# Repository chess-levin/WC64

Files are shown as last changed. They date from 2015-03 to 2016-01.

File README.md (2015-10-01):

# WC64
### Yet another wordclock project

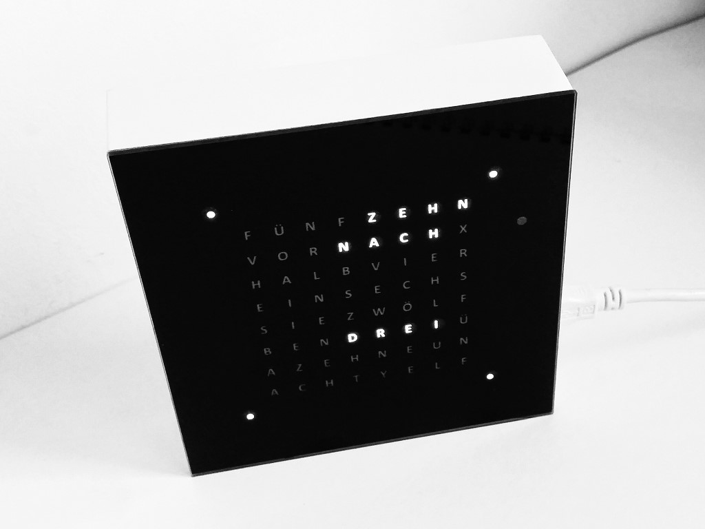
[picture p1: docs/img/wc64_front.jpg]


This is my version of a wordclock. I was trying out the arduino platform and this made so much fun, so I decided to build my own wordclock. The dimensions of my wordclock are approx. 11x11x3 cm. The front panel is hold by four strong neodym magnets. You can unclip it and turn it by 90 degress. This allows you to change the posing variant: You can hang the clock on the wall or set it on a shelf. The clock detects the environment brightness and adapts the brightness of the display to it. Find some videos of the clock on youtube [1] (https://youtu.be/Z6hiXQTgQTk), [2](https://www.youtube.com/watch?v=mQ0f72IIGkc), [3](https://www.youtube.com/watch?v=TP77dVIzgcs).

### Electronics

Techically it is based upon an [8x8 LED Matrix (WS2812B LEDs)](https://github.com/chess-levin/WC64/blob/master/docs/img/wc64_matrix.jpg), a real time clock (RTC DS3231 AT24C32 Memory Real Time Clock IIC Modul für Arduino PIC CP14003 B36) and an arduino nano board. In order to set time and date there are two push buttons inside the case.  The display is a multilayer stack of acralic glass, transparancy film, LED matrix and hard foam board. The power supply is a 2100mA USB power adapter, that connects to the arduino via mini USB cable.

### Structure

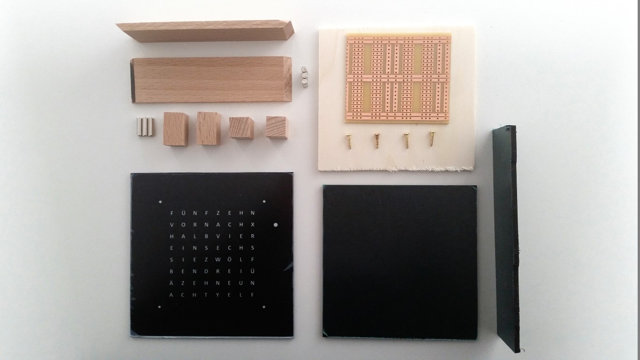
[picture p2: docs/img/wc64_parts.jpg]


The first challenge was to find a way to get [the mask](https://github.com/chess-levin/WC64/blob/master/docs/mask_final_dt.pdf) with the letters on the acrylic. For a transparency made by a cutting plotter the letters are to schmall. So I decided to have the mask printed on a transperency. The result was that the black parts were to translucent. To achieve a high contrast between the dark parts and the lighten letters I glued two transparencies together. One of the two transparencies has a self-adhesive side which it is glued to the acrylic.

The second challenge was to build a thin carrier board for the 68 LEDs and the light sensor. After some trial and error rountrips with wood I found the hard foam board. The hard foam is light, stable and most important it doesn't splinter when drilling the holes for the LEDs. The carrier board is fixed to the display with doubled sided tape.

The case is made of wood.

There are some more images, a pdf of the mask and a [circuit diagram](https://github.com/chess-levin/WC64/blob/master/docs/img/WC64_circuit.png) in the docs folder.

### Thanks

I found several ideas browsing the net for other wordclock projects. One was the [formatc1702](https://github.com/formatc1702) project of Daniel Rojas. He gave me the idea how to put all words into an 8x8 matrix. Thank you guys - keep on  wordclocking!

Have fun!

Any comments are welcome.

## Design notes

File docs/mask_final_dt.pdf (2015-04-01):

- ●
F | Ü | N | F | Z | E | H | N
V | O | R | N | A | C | H | X | ●
H | A | L | B | V | I | E | R
E | I | N | S | E | C | H | S
S | I | E | Z | W | Ö | L | F
B | E | N | D | R | E | I | Ü
Ä | Z | E | H | N | E | U | N
A | C | H | T | Y | E | L | F
- ●
- ●
F | Ü | N | F | Z | E | H | N
●
| V | O | R | N | A | C | H | X
H | A | L | B | V | I | E | R
E | I | N | S | E | C | H | S
S | I | E | Z | W | Ö | L | F
B | E | N | D | R | E | I | Ü
Ä | Z | E | H | N | E | U | N
A | C | H | T | Y | E | L | F
- ●

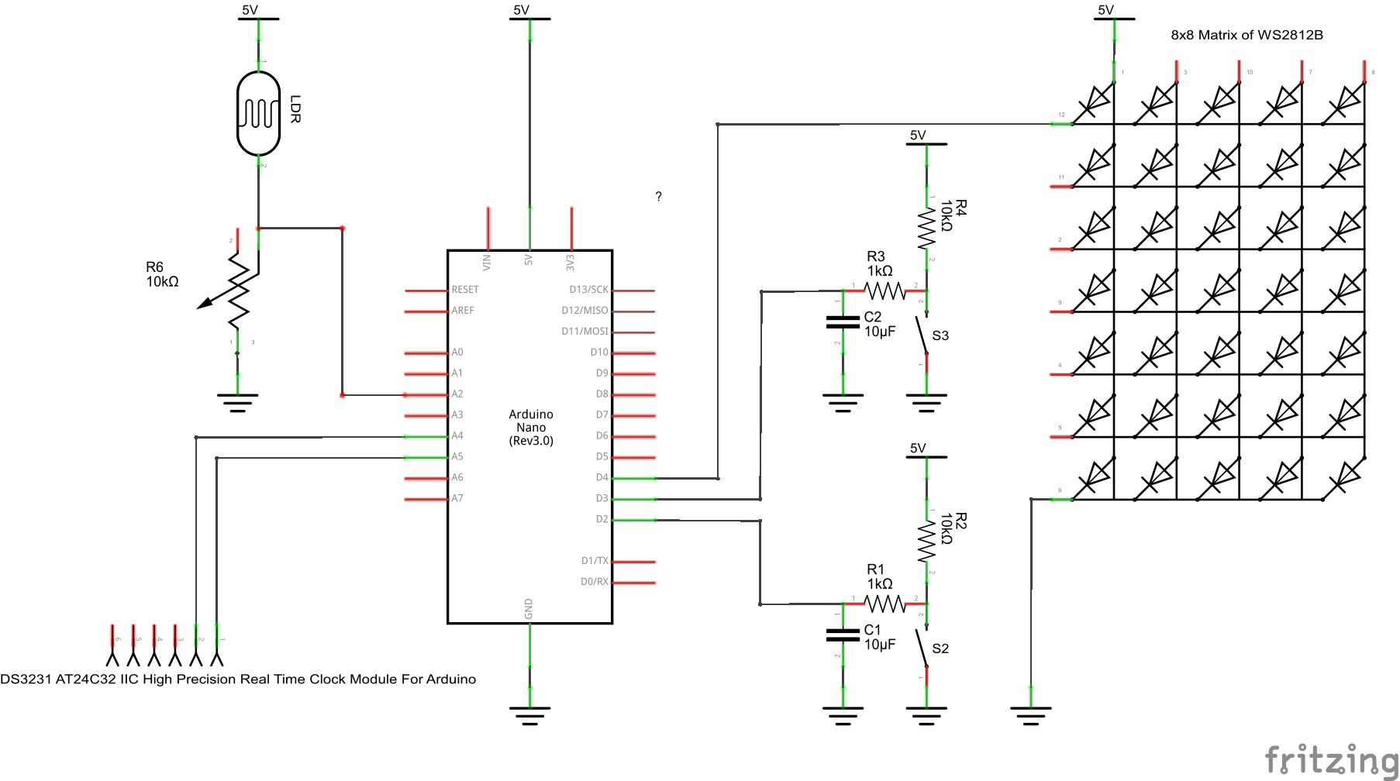
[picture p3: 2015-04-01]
docs/img/WC64_circuit.png

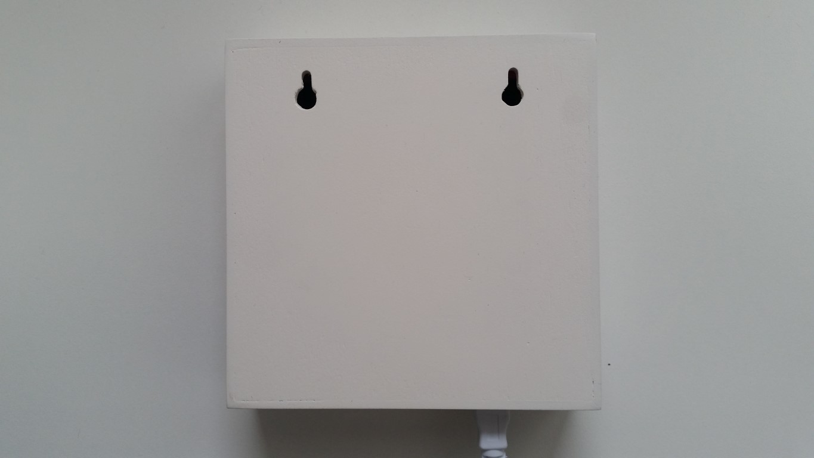
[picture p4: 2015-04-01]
docs/img/wc64_backside.jpg

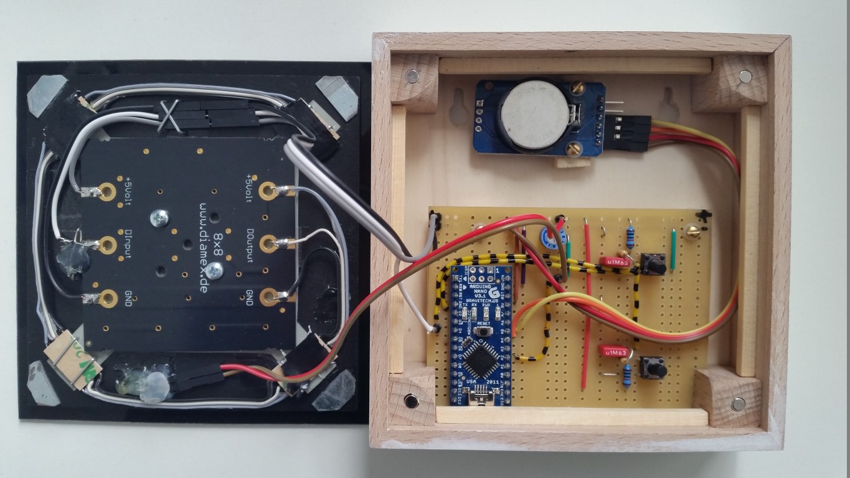
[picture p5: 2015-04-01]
docs/img/wc64_inside.jpg

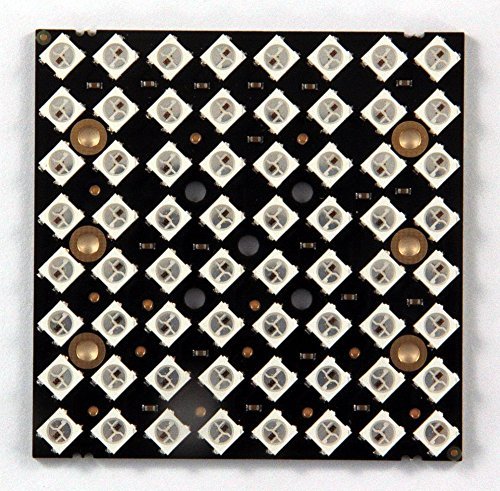
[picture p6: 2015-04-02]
docs/img/wc64_matrix.jpg

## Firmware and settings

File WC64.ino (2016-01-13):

/***************************************************************************************************************

 This sketch uses the following Libs
 
 * FastLED-3.0.3
 * ds3231-master
 
 
 (c) by Sven Scheil, 2015

*****************************************************************************************************************/

#include <avr/io.h>
#include <avr/pgmspace.h>
#include <config.h>
#include <ds3231.h>
#include <Wire.h>
#include <FastLED.h>

// Params for width and height
const uint8_t kMatrixWidth = 8;
const uint8_t kMatrixHeight = 8;
// Param for different pixel layouts
const bool kMatrixSerpentineLayout = true;
// Number of RGB LEDs in the strand
#define NUM_LEDS 68

// DC3231
#define BUFF_MAX 128
uint8_t time[8];
char recv[BUFF_MAX];
unsigned int recv_size = 0;

// Define the array of leds
CRGB leds[NUM_LEDS];
// Arduino pin used for Data
#define DATA_PIN 4

#define MAX(x, y) (((x) > (y)) ? (x) : (y))
#define MIN(x, y) (((x) < (y)) ? (x) : (y))

// Colors for display in different set modes and normal time mode
#define COLOR_NORMAL_DISPLAY CRGB( 255, 255, 255)
#define COLOR_SET_DISPLAY CRGB( 255, 136, 0)
#define COLOR_SET_DAY CRGB( 255, 0, 0); 
#define COLOR_SET_MONTH CRGB( 0, 255, 0); 
#define COLOR_SET_YEAR CRGB( 0, 0, 255);
#define LETTER_OFF 0

#define BTN_MIN_PRESSTIME 95    //doftware debouncing: ms button to be pressed before action
#define TIMEOUT_SET_MODE 30000  //ms no button pressed

#define SET_MODE_DUMMY -1
#define SET_MODE_OFF 0
#define SET_MODE_LEDTEST 1
#define SET_MODE_YEAR 2
#define SET_MODE_MONTH 3
#define SET_MODE_DAY 4
#define SET_MODE_HOURS 5
#define SET_MODE_5MINUTES 6
#define SET_MODE_1MINUTES 7
#define SET_MODE_MAX 7

volatile int setModeState = SET_MODE_OFF;

#define START_WITH_YEAR 2015  // start year setting with

#define MIN_BRIGHTNESS 4 
#define MAX_BRIGHTNESS 65

#define SET_BTN1_PIN 2      // set mode button; Interrupt 0 is on DIGITAL PIN 2!
#define SET_BTN2_PIN 3      // set value button; Interrupt 1 is on DIGITAL PIN 3!
#define SET_BTN1_IRQ 0      // set mode button; Interrupt 0 is on DIGITAL PIN 2!
#define SET_BTN2_IRQ 1      // set value button; Interrupt 1 is on DIGITAL PIN 3!

#define INTERNAL_LED_PIN 13

#define BRIGHNTNESS_SENSOR_PIN 2

#define TERM 255

const byte whone[] PROGMEM = {28,29,30,31,TERM};
const byte whtwo[] PROGMEM = {35,36,41,42,TERM};
const byte whthree[] PROGMEM = {41,42,43,44,TERM};
const byte whfour[] PROGMEM = {20,21,22,23,TERM};
const byte whfive[] PROGMEM = {39,40,55,56,TERM};
const byte whsix[] PROGMEM = {24,25,26,27,28,TERM};
const byte whseven[] PROGMEM = {32,33,34,47,46,45,TERM};
const byte wheight[] PROGMEM = {63,62,61,60,TERM};
const byte whnine[] PROGMEM = {52,53,54,55,TERM};
const byte whten[] PROGMEM = {49,50,51,52,TERM};
const byte wheleven[] PROGMEM = {56,57,58,TERM};
const byte whtwelve[] PROGMEM = {35,36,37,38,39,TERM};

const byte* const whours[] PROGMEM = {whone, whtwo, whthree, whfour, whfive, whsix, whseven, wheight, whnine, whten, wheleven, whtwelve};

const byte wmone[] PROGMEM = {66,TERM};
const byte wmtwo[] PROGMEM = {66,65,TERM};
const byte wmthree[] PROGMEM = {66,65,64,TERM};
const byte wmfour[] PROGMEM = {66,65,64,67,TERM};
const byte wmfive[] PROGMEM = {0,1,2,3,TERM};
const byte wmten[] PROGMEM = {4,5,6,7,TERM};
const byte wmfiveten[] PROGMEM = {0,1,2,3,4,5,6,7,TERM};

#define mfive_idx 4
#define mten_idx 5
#define mfiveten_idx 6

const byte* const wminutes[] PROGMEM = {wmone, wmtwo, wmthree, wmfour, wmfive, wmten, wmfiveten};

const byte wto[] PROGMEM = {13,14,15,TERM};
const byte wpast[] PROGMEM = {9,10,11,12,TERM};
const byte whalf[] PROGMEM = {16,17,18,19,TERM};

#define mto_idx 0
#define mpast_idx 1
#define mhalf_idx 2

const byte* const wtime[] PROGMEM = {wto, wpast, whalf};

byte letterMatrix[NUM_LEDS];

uint8_t minLastDisplayed = 0;

long lastPressedTime = 0;
struct ts t;

void (*animationCalback)();

#define UPDATES_PER_SECOND 8

byte startpoint[] = {0,2,3,0,1,0,2};
int averageBrigtness[] = {500,500,500,500,500,500};
byte averageBrigtnessIdx = 0;

void setup() {
  delay(3000);

  randomSeed(analogRead(0));

  FastLED.addLeds<WS2812B, DATA_PIN, GRB>(leds, NUM_LEDS);
  FastLED.clear();
  
  pinMode(INTERNAL_LED_PIN, OUTPUT);
  digitalWrite(INTERNAL_LED_PIN, LOW);  // turn LED OFF
  
  attachInterrupt(SET_BTN1_IRQ, initSetMode, RISING);
//  attachInterrupt(SET_BTN2_IRQ, setValue, RISING);
 
  pinMode(SET_BTN1_PIN, INPUT);     
  pinMode(SET_BTN2_PIN, INPUT);

  Serial.begin(9600);
  
  Wire.begin(); // init Wire Library
  DS3231_init(DS3231_INTCN);
  memset(recv, 0, BUFF_MAX);
}

void loop() {
  FastLED.show();                        // see https://github.com/FastLED/FastLED/wiki/FastLED-Temporal-Dithering

  if (setModeState == SET_MODE_OFF) {
    animationCalback = &showMatrixAnimation;
//    animationCalback = &showNoAnimation;
    getRTCData(&t);
        
    if (t.min != minLastDisplayed) {
      minLastDisplayed = t.min;
      showTime(t.hour, t.min);
    }
    delay(5000);
    readBrightnessSensor();
  
  } else {
     Serial.print(F("setModeState in main loop: "));
     Serial.println(setModeState);
     animationCalback = &showNoAnimation;
     queryButtonLoop();
     showTime(t.hour, t.min);
  }
  
}


void showAnimation( void (*animation)() ) {
  animation();
  resetLetterMatrix();
}

void showTime(int hours, int minutes) {
  Serial.print(F("Show time: "));
  printTime(hours, minutes);
  int hcorrection = showMinutes(minutes);
  showHours(hours + hcorrection);
  showAnimation(animationCalback);
}

void checkButton(byte mask, byte *pressed, byte btnPin, void (*action)() ) {
    if (digitalRead(btnPin) == LOW) {
      *pressed |= mask;
    } else if ((*pressed & mask) == mask) {
      lastPressedTime = millis();
      action();
      *pressed &= ~mask;
    }
}

void queryButtonLoop() {
  byte pressed = 0b00000000;
  lastPressedTime = millis();
  
  while ((millis() - lastPressedTime < TIMEOUT_SET_MODE) && (setModeState > SET_MODE_OFF)){
    checkButton(0b000001, &pressed, SET_BTN1_PIN, &nextSetMode);
    checkButton(0b000010, &pressed, SET_BTN2_PIN, &nextStep);
  }
  
  if (setModeState > SET_MODE_OFF) {
    Serial.println(F("timeout"));
    resetModeState();
  }
}

void initSetMode() {
  detachInterrupt(SET_BTN1_IRQ);
  Serial.println(F("initSetMode "));

  nextSetMode();
}

void nextStep() {
  if (setModeState == SET_MODE_DAY) {
    Serial.println(F("Set next day"));
    t.mday+=1;
    if (t.mday > 31) t.mday = 1;
    showDay(t.mday);
  } else   if (setModeState == SET_MODE_MONTH) {
    Serial.println(F("Set next month"));
    t.mon+=1;
    if (t.mon > 12) t.mon = 1;
    showMonth(t.mon);
  } else   if (setModeState == SET_MODE_YEAR) {
    Serial.println(F("Set next year"));
    t.year+=1;
    if (t.year > 2020) t.year = START_WITH_YEAR;
    showYear(t.year);
  } else   if (setModeState == SET_MODE_HOURS) {
    Serial.println(F("Set next hour"));
    t.hour++;
    if (t.hour > 23) t.hour = 0;
    showTime(t.hour, t.min);
  } else   if (setModeState == SET_MODE_5MINUTES) {
    Serial.println(F("Set next 5 minute word"));
    t.min+=5;
    if (t.min > 55) t.min = 0;
    showTime(t.hour, t.min);
  } else   if (setModeState == SET_MODE_1MINUTES) {
    Serial.println(F("Set next minute dot"));
    t.min+=1;
    if (t.min %5 == 0) t.min -= 5;
    showTime(t.hour, t.min);
  } else if (setModeState == SET_MODE_LEDTEST) {
    if ((t.min%5) == 0) {
      t.min+=2;
    } else {
      t.min+=3;
    }
    if (t.min > 60) { 
      t.min = 0;
    }
    showTime(t.hour, t.min);
  } else {
    Serial.println(F("Unknown setModeState"));
  }
}

void nextSetMode() {
  setModeState++;

  Serial.print(F("Switching to setModeState: "));
  Serial.println(setModeState);
  
  if (setModeState == SET_MODE_HOURS) {
    t.hour=12;
    t.min=0;
    t.sec=0;
    showTime(t.hour, t.min);
  } else if (setModeState == SET_MODE_5MINUTES) {
    t.min=5;
    showTime(t.hour, t.min);
  } else if (setModeState == SET_MODE_1MINUTES) {
    t.min++;
    showTime(t.hour, t.min);    
  } else if (setModeState == SET_MODE_LEDTEST) {
    testShowAllWordsSeq();
  } else if (setModeState == SET_MODE_DAY) {
    showDay(t.mday);
  } else if (setModeState == SET_MODE_MONTH) {
    showMonth(t.mon);
  } else if (setModeState == SET_MODE_YEAR) {
    t.mday;
    t.mon;
    t.year=START_WITH_YEAR;
    showYear(t.year);
  }

  if (setModeState > SET_MODE_MAX) {
    Serial.println(F("===> Setting new Date & Time to: "));
    printRTCDataStruct(&t);
    DS3231_set(t);
    setModeState = SET_MODE_DUMMY;
    attachInterrupt(SET_BTN1_IRQ, initSetMode, RISING);
  }
}

void resetModeState() {
  if (setModeState != SET_MODE_OFF) {
    setModeState = SET_MODE_OFF;
    Serial.println(F("Resetting setModeState after timeout pressing no button. Fallback to old Time & Date."));
    attachInterrupt(SET_BTN1_IRQ, initSetMode, RISING);
  }
}

void getRTCData(struct ts *t) {
    float temperature;
    char buff[BUFF_MAX];
   
    DS3231_get(t); //Get time

    printRTCDataStruct(t);
}


// If there are <= 20 minutes in a hour a correction value of 1 is returned
// to be added to the hour
byte showMinutes(int minutes) {
  
  int tidx = -1; // 5, 10, 15
  int ridx = -1; // 1 past , 2 to 
  int qidx = -1; // 1 half
  int showMinutes = minutes;
  
  if (minutes == 0) {
  } else if (minutes < 5) {
    ridx = mpast_idx;
  } else if (minutes < 10) {
    tidx = mfive_idx;
    ridx = mpast_idx;
  } else if (minutes < 15) {
    tidx = mten_idx;
    ridx = mpast_idx;
  } else if (minutes < 20) {
    tidx = mfiveten_idx;
    ridx = mpast_idx;
  } else if (minutes == 20) {
    tidx = mten_idx;
    ridx = mto_idx;
    qidx = mhalf_idx;
  } else if (minutes < 25) {
    tidx = mfive_idx;
    ridx = mto_idx;
    qidx = mhalf_idx;
    showMinutes = 25 - minutes;
  } else if (minutes == 25) {
    tidx = mfive_idx;
    ridx = mto_idx;
    qidx = mhalf_idx;
  } else if (minutes < 30) {
    ridx = mto_idx;
    qidx = mhalf_idx;
    showMinutes = 30 - minutes;
  } else if (minutes == 30) {
    qidx = mhalf_idx;  
  } else if (minutes < 35) {
    qidx = mhalf_idx;  
    ridx = mpast_idx;
  } else if (minutes < 40) {
    tidx = mfive_idx;
    ridx = mpast_idx;
    qidx = mhalf_idx;  
  } else if (minutes == 40) {
    tidx = mten_idx;
    ridx = mpast_idx;
    qidx = mhalf_idx;  
  } else if (minutes < 45) {
    tidx = mfiveten_idx;
    ridx = mto_idx;
    showMinutes = 45 - minutes;
  } else if (minutes == 45) {
    tidx = mfiveten_idx;
    ridx = mto_idx;
  } else if (minutes < 50) {
    tidx = mten_idx;
    ridx = mto_idx;
    showMinutes = 50 - minutes;
  } else if (minutes == 50) {
    tidx = mten_idx;
    ridx = mto_idx;
  } else if (minutes < 55) {
    tidx = mfive_idx;
    ridx = mto_idx;
    showMinutes = 55 - minutes;
  } else if (minutes == 55) {
    tidx = mfive_idx;
    ridx = mto_idx;
  } else if (minutes < 60) {
    showMinutes = 60 - minutes;
    ridx = mto_idx;
  }
  
  if (tidx>=0) {
    showWord((byte*) pgm_read_word (&wminutes[tidx]));
  }
  
  if (ridx>=0) {
    showWord((byte*) pgm_read_word (&wtime[ridx]));
  }

  if (qidx>=0) {
    showWord((byte*) pgm_read_word (&wtime[qidx]));
  }

  if ((showMinutes % 5) > 0) {
    showWord((byte*) pgm_read_word (&wminutes[(showMinutes % 5)-1]));
  }
  
  if (minutes < 20) {
    return 0;
  } else {
    return 1;
  }
}

void showHours(int hours) {
  if (hours > 12) {
    hours -= 12;
  }
  
  showWord((byte*) pgm_read_word (&whours[hours-1]));
}
  
void testShowAllWordsSeq() {
  FastLED.clear();  
  showWord((byte*) pgm_read_word (&wminutes[0]));
  showWord((byte*) pgm_read_word (&wminutes[1]));
  showWord((byte*) pgm_read_word (&wminutes[2]));
  showWord((byte*) pgm_read_word (&wminutes[3]));
  showWord((byte*) pgm_read_word (&wminutes[mfive_idx]));
  showWord((byte*) pgm_read_word (&wminutes[mten_idx]));
  showWord((byte*) pgm_read_word (&wminutes[mfiveten_idx]));
  showWord((byte*) pgm_read_word (&wtime[mto_idx]));
  showWord((byte*) pgm_read_word (&wtime[mpast_idx])); 
  showWord((byte*) pgm_read_word (&wtime[mhalf_idx]));
  showWord((byte*) pgm_read_word (&whours[0]));
  showWord((byte*) pgm_read_word (&whours[1])); 
  showWord((byte*) pgm_read_word (&whours[2]));
  showWord((byte*) pgm_read_word (&whours[3]));
  showWord((byte*) pgm_read_word (&whours[4]));
  showWord((byte*) pgm_read_word (&whours[5])); 
  showWord((byte*) pgm_read_word (&whours[6]));
  showWord((byte*) pgm_read_word (&whours[7])); 
  showWord((byte*) pgm_read_word (&whours[8]));
  showWord((byte*) pgm_read_word (&whours[9])); 
  showWord((byte*) pgm_read_word (&whours[10]));
  showWord((byte*) pgm_read_word (&whours[11]));
  FastLED.show();  
}

void showWord(const byte* wordLeds) {
  byte idx = pgm_read_byte(wordLeds);
  
  while (idx < TERM) {
    letterMatrix[idx] = 1; 
    wordLeds++;
    idx = pgm_read_byte( wordLeds);
  }
}

void showDay(int day) {
  FastLED.clear();
  for(byte i = 0; i < day; i++) {
    leds[i] = COLOR_SET_DAY; 
  }
  FastLED.show();
}
  
void showMonth(int month) {
  FastLED.clear();
  for(byte i = 0; i < month; i++) {
    leds[i] = COLOR_SET_MONTH; 
  }
  FastLED.show();
}
  
void showYear(int year) {
  FastLED.clear();
  for(byte i = 0; i < year-2000; i++) {
    leds[i] = COLOR_SET_YEAR; 
  }
  FastLED.show();
}

void readBrightnessSensor() {
  char buffer[26];
  int sum = 0;

  averageBrigtness[averageBrigtnessIdx] = analogRead(BRIGHNTNESS_SENSOR_PIN);

  Serial.print(F("Brightness Measures : "));

  averageBrigtnessIdx++;
  if (averageBrigtnessIdx >= (sizeof(averageBrigtness)/sizeof(int))) averageBrigtnessIdx = 0;
  
  for (int i = 0; i < (sizeof(averageBrigtness)/sizeof(int)); i++) {
    Serial.print(averageBrigtness[i]);
    Serial.print(", ");  
    sum += averageBrigtness[i];
  }

  int average = sum / (sizeof(averageBrigtness)/sizeof(int));
  Serial.print(F("Average of Measures: "));
  Serial.println(average);  

  int brightnessVal = map(average, 0, 1023, MIN_BRIGHTNESS, MAX_BRIGHTNESS);
  
  FastLED.setBrightness(brightnessVal);

  sprintf(buffer, "Brightness %d => %d", average, brightnessVal);
  Serial.println(buffer);
}

void printRTCDataStruct(struct ts *t) {
   printDate(t);
   printTime(t);
}

void printTime(int hours, int minutes) {
    char buffer [6]; 
    sprintf(buffer, "%02d:%02d", hours, minutes);
    Serial.println(buffer);
}

void printTime(struct ts *t) {
  char buffer [12]; 
  sprintf(buffer, "%02d:%02d:%02d", (uint8_t) t->hour, t->min, t->sec);
  Serial.println(buffer);
}

void printDate(struct ts *t)
{
   char buffer [15];
   sprintf(buffer, "%02d.%02d.%04d, ", t->mday, t->mon, t->year);
   Serial.print(buffer);
}

void showNoAnimation() {
  FastLED.clear();
  for(byte i = 0; i < NUM_LEDS; i++) {
      if (letterMatrix[i] == 1) {
          leds[i] = CRGB(255,255,255);
      }
  }
  FastLED.show();
}

void showMatrixAnimation() {
  Serial.println("showMatrixAnimation()");
  setMatrixAnimStartpoints();
  
  for (byte loopCount = 0; loopCount < kMatrixHeight+3; loopCount++) {
    matrixRainAnimation();
    FastLED.show();
    FastLED.delay(1000 / UPDATES_PER_SECOND);
  }
}

void matrixRainAnimation() {
    Serial.println("matrixRainAnimation()");
    
    for (byte x = 0; x < kMatrixWidth; x++) {
      matrixRainAnimCol(startpoint[x]++, x);
  }
}

void matrixRainAnimCol(int currentLine, byte x) {
  byte startline = MAX(currentLine - 2, 0);
  byte endline = MIN(kMatrixHeight, currentLine + 1);
  
  for (byte y = 0; y < kMatrixHeight; y++) {
  
    if (y == 0)  {
      if (letterMatrix[66] == 1) {
        leds[66] = CRGB(255,255,255);
      } else {
        leds[66] = CRGB::Black;
      }
      if (letterMatrix[65] == 1) {
        leds[65] = CRGB(255,255,255);
      } else {
        leds[65] = CRGB::Black;
      }
    }

    if (y == kMatrixHeight-1)  {
      if (letterMatrix[64] == 1) {
        leds[64] = CRGB(255,255,255);
      } else {
        leds[64] = CRGB::Black;
      }
      if (letterMatrix[67] == 1) {
        leds[67] = CRGB(255,255,255);
      } else {
        leds[67] = CRGB::Black;
      }
    } 
   
    if ((y >= startline) && (y < endline) ) {
      if ((y+1 == endline) && (endline < kMatrixHeight))
        leds[xy2LedIndex(x, y)] = CRGB(255,255,255);
      else 
        leds[xy2LedIndex(x, y)] = CRGB(45, 45, 45);
    } else {
      if (y < endline) {
        if (letterMatrix[xy2LedIndex(x, y)] == 1) {
          leds[xy2LedIndex(x, y)] = CRGB(255,255,255);
        } else {  
          leds[xy2LedIndex(x, y)] = CRGB::Black;
        }
      }
    }
    
  }
}

void setMatrixAnimStartpoints() {
  startpoint[0] = random(3);
  startpoint[1] = random(3);
  startpoint[2] = random(3);
  startpoint[3] = random(3);
  startpoint[4] = random(3);
  startpoint[5] = random(3);
  startpoint[6] = random(3);
  startpoint[7] = random(3);
}


void resetLetterMatrix() {
  for (int i=0; i <NUM_LEDS; i++) {
    letterMatrix[i] = LETTER_OFF;
  }
}

uint16_t xy2LedIndex( uint8_t x, uint8_t y)
{
  uint16_t i;
  
  if( kMatrixSerpentineLayout == false) {
    i = (y * kMatrixWidth) + x;
  }

  if( kMatrixSerpentineLayout == true) {
    if( y & 0x01) {
      // Odd rows run backwards
      uint8_t reverseX = (kMatrixWidth - 1) - x;
      i = (y * kMatrixWidth) + reverseX;
    } else {
      // Even rows run forwards
      i = (y * kMatrixWidth) + x;
    }
  }
 
  return i;
}

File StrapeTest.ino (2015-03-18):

#include <config.h>
#include <ds3231.h>
#include <Wire.h>
#include <FastLED.h>

// Number of RGB LEDs in the strand
#define NUM_LEDS 68
const uint8_t NUM_ROWS  = 8;

// DC3231
#define BUFF_MAX 128
uint8_t time[8];
char recv[BUFF_MAX];
unsigned int recv_size = 0;

// Define the array of leds
CRGB leds[NUM_LEDS];
// Arduino pin used for Data
#define DATA_PIN 2

#define BTN_MIN_PRESSTIME 150   //ms button to be pressed before action
#define TIMEOUT_SET_MODE 60000  //ms no button pressed

#define SET_MODE_OFF 1
#define SET_MODE_LEDTEST 2
#define SET_MODE_DAY 4
#define SET_MODE_MONTH 8
#define SET_MODE_YEAR 16
#define SET_MODE_HOURS 32
#define SET_MODE_5MINUTES 256
#define SET_MODE_1MINUTES 512
#define SET_MODE_MAX 512
#define START_WITH_YEAR 2015

#define MIN_BRIGHTNESS 25        // 16 is minimum
#define MAX_BRIGHTNESS 122

#define SET_BTN1_PIN 7
#define SET_BTN2_PIN 6
#define INTERNAL_LED_PIN 13

#define BRIGHNTNESS_SENSOR_PIN 2

uint8_t setMode = SET_MODE_OFF;
int brightnessVal = 37;  // Default hue

int wmone[] = {66};
int wmtwo[] = {66,65};
int wmthree[] = {66,65,64};
int wmfour[] = {66,65,64,67};
int wmfive[] = {0,1,2,3};
int wmten[] = {4,5,6,7};
int wmfiveten[] = {0,1,2,3,4,5,6,7};
int wto[] = {13,14,15};
int wpast[] = {9,10,11,12};
int whalf[] = {16,17,18,19};
int whone[] = {28,29,30,31};
int whtwo[] = {35,36,41,42};
int whthree[] = {41,42,43,44};
int whfour[] = {20,21,22,23};
int whfive[] = {39,40,55,56};
int whsix[] = {24,25,26,27,28};
int whseven[] = {32,33,34,47,46,45};
int wheight[] = {63,62,61,60};
int whnine[] = {52,53,54,55};
int whten[] = {49,50,51,52};
int wheleven[] = {56,57,58};
int whtwelve[] = {35,36,37,38,39};

void setup() {
  FastLED.addLeds<WS2812B, DATA_PIN, GRB>(leds, NUM_LEDS);
  
  pinMode(INTERNAL_LED_PIN, OUTPUT);
  pinMode(SET_BTN2_PIN, INPUT);
  digitalWrite(SET_BTN2_PIN, HIGH); // connect internal pull-up
  pinMode(SET_BTN1_PIN, INPUT);     // uses external pull-up
  digitalWrite(INTERNAL_LED_PIN, LOW);  // turn LED OFF

  Serial.begin(9600);  
  Wire.begin(); // init Wire Library
  DS3231_init(DS3231_INTCN);
  memset(recv, 0, BUFF_MAX);
  
  //Serial.println("Setting time");
  //           TssmmhhWDDMMYYYY aka set time
  //parse_cmd("T001919631012015",16);
}

void loop() {
    struct ts t;
    
    if (setMode == SET_MODE_OFF) {
      hueSensor();
      getRTCData(&t);
      showTime(t.hour, t.min);
    }

    idleLoop(&t);
    
    //showTestTimes();
}

void idleLoop(struct ts *t) {
    long startTime = millis();
    long pressedTime1 = 0;
    long pressedTime2 = 0;
    long lastPressedTime = 0;
    
    while (millis() - startTime < 10000) {
      
      int val1 = digitalRead(SET_BTN1_PIN);
      if (val1 == LOW) {      // Button pressed
       if (pressedTime1 == 0) {
          pressedTime1 = millis();
          lastPressedTime = pressedTime1;
       }
      } else {               // Button released
        if (pressedTime1 > 0) {
          long duration = millis() - pressedTime1;
          if (duration > BTN_MIN_PRESSTIME) {
            nextSetMode(t);
          }
        }
        pressedTime1 = 0;
      }

      int val2 = digitalRead(SET_BTN2_PIN);
      if (val2 == LOW) {      // Button pressed
       if (pressedTime2 == 0) {
          pressedTime2 = millis();
          lastPressedTime = pressedTime2;
       }
      } else {               // Button released
        if (pressedTime2 > 0) {
          long duration = millis() - pressedTime2;
          if (duration > BTN_MIN_PRESSTIME) {
            nextStep(t);
          }
        }
        pressedTime2 = 0;
      }
    }
    if (millis() - lastPressedTime > TIMEOUT_SET_MODE) {
      resetSetMode();
    }
}

void nextStep(struct ts *t) {
  confirmationLEDFlash();
  if (setMode == SET_MODE_DAY) {
    Serial.println("Set next day");
    showDay(t->mday++);
  } else   if (setMode == SET_MODE_MONTH) {
    Serial.println("Set next month");
    showMonth(t->mon++);
  } else   if (setMode == SET_MODE_YEAR) {
    Serial.println("Set next year");
    showYear(t->year++);
  } else   if (setMode == SET_MODE_HOURS) {
    Serial.println("Set next hour");
    t->hour++;
    if (t->hour > 23) t->hour = 0;
    showTime(t->hour, t->min);
  } else   if (setMode == SET_MODE_5MINUTES) {
    Serial.println("Set next 5 minute word");
    t->min+=5;
    if (t->min > 55) t->min = 0;
    showTime(t->hour, t->min);
  } else   if (setMode == SET_MODE_1MINUTES) {
    Serial.println("Set next minute dot");
    t->min+=1;
    if (t->min > 60) t->min = 0;
    showTime(t->hour, t->min);
  } else   if (setMode == SET_MODE_LEDTEST) {
    if ((t->min%5) == 0) {
      t->min+=2;
    } else {
      t->min+=3;
    }
    if (t->min > 60) { 
      t->min = 0;
    }
    showTime(t->hour, t->min);
  } else {
    Serial.println("Unknown setMode");
  }
}

void nextSetMode(struct ts *t) {
  confirmationLEDFlash();
  setMode = setMode << 1;
  
  if (setMode == SET_MODE_HOURS) {
    t->hour=12;
    t->min=0;
    t->sec=0;
    showTime(t->hour, t->min);
  } else if (setMode == SET_MODE_LEDTEST) {
    t->hour=12;
    t->min=0;
    t->sec=0;
    showAllWordsSeq();
  } else if (setMode == SET_MODE_DAY) {
    t->mday;
    t->mon=0;
    t->year=START_WITH_YEAR;
    showDay(t->mday);
  } else if (setMode == SET_MODE_MONTH) {
    showMonth(t->mon);
  } else if (setMode == SET_MODE_YEAR) {
    showYear(t->year);
  }

  if (setMode > SET_MODE_MAX) {
    setMode = SET_MODE_OFF;
  }
  
  Serial.print("Switching to setMode: ");
  Serial.println(setMode);
  if (setMode == SET_MODE_OFF) {
    DS3231_set(*t);
    digitalWrite(INTERNAL_LED_PIN, LOW);
  } else {
    digitalWrite(INTERNAL_LED_PIN, HIGH);
  }

}

void confirmationLEDFlash() {
  digitalWrite(INTERNAL_LED_PIN, LOW);
  delay (200);
  digitalWrite(INTERNAL_LED_PIN, HIGH);
}

void resetSetMode() {
  if (setMode != SET_MODE_OFF) {
    setMode = SET_MODE_OFF;
    Serial.println("Resetting setMode after timeout pressing no button. Fallback to old Time & Date.");
    digitalWrite(INTERNAL_LED_PIN, LOW);
  }
}

void getRTCData(struct ts *t) {
    float temperature;
    char tempF[6];
    char buff[BUFF_MAX];
   
    DS3231_get(t); //Get time
    parse_cmd("C",1);
    temperature = DS3231_get_treg(); //Get temperature
    dtostrf(temperature, 5, 1, tempF);

    Serial.print(t->mday);
    
    printMonth(t->mon);
    
    Serial.print(t->year);
    Serial.print(", ");   
    Serial.print(t->hour);
    Serial.print(":");
    if(t->min<10)
    {
      Serial.print("0");
    }
    Serial.print(t->min);
    Serial.print(":");
    if(t->sec<10)
    {
      Serial.print("0");
    }
    Serial.print(t->sec);
    
    Serial.print(' ');
    Serial.print(tempF);
    Serial.print((char)223);
    Serial.print("C ");
}
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

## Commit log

2015-03-18 Set Date/Time corrected
    StrapeTest.ino renamed to WC64.ino
    Set Date/Time Function corrected
    [WC64.ino]
2015-03-18 Changed datatype of word LED Arrays
2015-03-18 Inserted showWordMacro
    To hide the terrible sizeof calculation :-1:
2015-03-21 Added termination token into LED address arrays
2015-03-21 LED addresses as array of arrays
    In order to save memory. That doesn't worked out. It seems only a good
    training for c pointer arithmetic.
    [WC64.ino]
2015-03-31 Added Hardware Debouncing & Psh Btns trigger IRQ
    Hardware Debouncing as descirbed here
    https://www.youtube.com/watch?v=tmjuLtiAsc0 but without Schmitt Trigger
    Connected Buttons to Pin 2 & 3 in order make use of IRQ
2015-04-01 Added circuit diagram
    [WC64.fzz]
2015-04-02 Added LED matrix image
2015-05-19 Matrix style animation
    Falling letters deleting current time. New time appears on empty screen.
2016-01-11 IndexOutOfBounds error fixed
    setMatrixAnimStartpoints() used max index 8 instead of 7 for startpoint
    array
    [WC64.ino]
2016-01-13 Optimized Brightness Adaption
    Sampling the brightness sensor every 5 sec and calculate an average
    brightness of the last 6 samples.
